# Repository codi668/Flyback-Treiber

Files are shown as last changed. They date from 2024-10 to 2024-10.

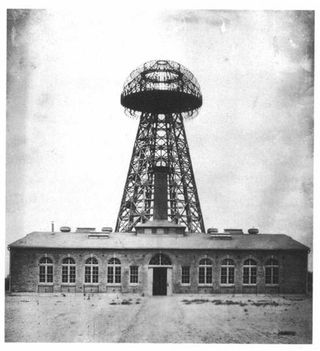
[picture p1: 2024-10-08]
Libaries/wardencliif.jpeg

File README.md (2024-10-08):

# Flyback Musik-Treiber

Dieses Projekt verwendet einen Flyback-Treiber, um Musiksignale zu erzeugen und diese über Zeilentrafos auszugeben. Der Flyback-Treiber moduliert das Audiosignal und überträgt es an den Zeilentrafo, der die Musik in hörbare Geräusche umwandelt. Dieses Setup eignet sich für experimentelle Audioprojekte oder künstlerische Installationen.

## Funktionsweise

Der Flyback-Treiber empfängt analoge Audiosignale (zum Beispiel von einem Musikplayer oder einem Synthesizer) und nutzt einen Flyback-Transformator, um diese auf Hochspannungsniveau zu übertragen. Der Zeilentrafo empfängt das modulierte Signal und wandelt es in hörbare Schwingungen um, die als Musik oder Geräusche wahrgenommen werden.

## Features

- **Audio-Ausgabe:** Musik wird über Zeilentrafos ausgegeben.
- **Einfache Integration:** Der Treiber lässt sich mit verschiedenen Audioquellen und Verstärkern verbinden.
- **Verstellbare Lautstärke:** Die Lautstärke kann durch Anpassung der Eingangssignale gesteuert werden.
- **Experimentelles Design:** Ideal für künstlerische Projekte oder Sound-Installationen.

## Komponenten

1. **Flyback-Treiber-Modul**: Ein handelsübliches Flyback-Modul, das für die Hochspannungssteuerung verwendet wird.
2. **Zeilentrafo**: Ein Transformator, der zur Erzeugung der hörbaren Töne verwendet wird.
3. **Audioquelle**: Ein Gerät, das über 3,5mm Klinkenanschluss Musik wiedergibt (z. B. Smartphone, Laptop, etc.).
4. **Stromversorgung**: Ein Netzteil, das 12V bis 24V DC liefert (je nach Flyback-Modul).
5. **Kabel**: Zur Verbindung der Audioquelle, des Flyback-Treibers und des Zeilentrafos.

## Installationsanleitung

### Benötigte Materialien

- **Flyback-Treiber-Modul** (z.B. aus einem alten CRT-Monitor oder TV)
- **Zeilentrafo** (aus einem Fernseher oder Monitor)
- **Audioquelle** (mit 3,5mm Klinkenanschluss)
- **Netzteil** (12V-24V DC, abhängig vom Flyback-Modul)
- **Kabel und Stecker** (zur Verbindung der Komponenten)
- **Sicherheitsvorkehrungen** (Isoliermaterialien und Schutzvorkehrungen gegen Hochspannung)

### Schritt-für-Schritt-Anleitung

1. **Flyback-Treiber anschließen**:
   - Verbinde den Eingang des Flyback-Moduls mit einer 12V bis 24V DC-Stromquelle.
   - Verbinde das Audioeingangssignal (z. B. über einen 3,5mm Klinkenstecker) mit der Audioquelle (Smartphone, Laptop, etc.).

2. **Zeilentrafo anschließen**:
   - Der Ausgang des Flyback-Transformators wird an die Eingänge des Zeilentrafos angeschlossen.

3. **Testen**:
   - Spiele Musik von deiner Audioquelle ab und höre, wie das Signal über den Zeilentrafo ausgegeben wird.

## Sicherheitshinweise

- **Hochspannung**: Der Flyback-Treiber erzeugt Hochspannungen. Arbeite daher sehr vorsichtig und befolge alle Sicherheitsvorkehrungen, um Verletzungen durch Stromschläge zu vermeiden.
- **Isolierung**: Stelle sicher, dass alle Hochspannungsleitungen gut isoliert sind und keine Kurzschlüsse entstehen.
- **Schutzbrille und Handschuhe**: Trage immer Schutzbrille und isolierende Handschuhe, wenn du mit Hochspannung arbeitest.

## Anwendungen

- **Experimentelle Musikprojekte**: Nutze den Flyback-Treiber zur Erzeugung einzigartiger Klänge in einer Musikinstallation.
- **Kunstinstallationen**: Setze die Technologie in interaktive oder künstlerische Audioprojekte ein.
- **Prototyping**: Nutze das Setup als Grundlage für eigene Experimente im Bereich Audio- und Elektrotechnik.

## Lizenz

Dieses Projekt ist unter der MIT-Lizenz lizenziert. Siehe [LICENSE](LICENSE) für weitere Details.

## Kontakt

- **E-Mail:** thomas.gruber@htlstp.at
- **GitHub:** github.com/codi668

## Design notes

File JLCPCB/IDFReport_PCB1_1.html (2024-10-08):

Altium customize

# IDF File Translation Report

Date: | | 02.10.2024
Time: | | 19:26:28
Elapsed Time: | | 00:00:00
PCB Filename | : | D:\privat\Altium\Flyback\PCB1.PcbDoc
IDF Board Filename | : | C:\Users\t2022\Downloads\PCB1_1.brd
IDF Library Filename | : | C:\Users\t2022\Downloads\PCB1_1.pro

Errors

Back to top

Warnings

Back to top

Save Warnings

Back to top

Save Errors

Back to top

Export Warnings

Back to top

Export Errors

Back to top

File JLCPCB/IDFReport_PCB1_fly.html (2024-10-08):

Altium customize

# IDF File Translation Report

Date: | | 02.10.2024
Time: | | 19:20:07
Elapsed Time: | | 00:00:00
PCB Filename | : | D:\privat\Altium\Flyback\PCB1.PcbDoc
IDF Board Filename | : | C:\Users\t2022\Downloads\PCB1_fly.brd
IDF Library Filename | : | C:\Users\t2022\Downloads\PCB1_fly.pro

Errors

Back to top

Warnings

Back to top

Save Warnings

Back to top

Save Errors

Back to top

Export Warnings

Back to top

Export Errors

Back to top

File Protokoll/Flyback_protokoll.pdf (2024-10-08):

# Flyback Treiber

By Thomas Gruber

## Inhaltsverzeichnis

## Idee:

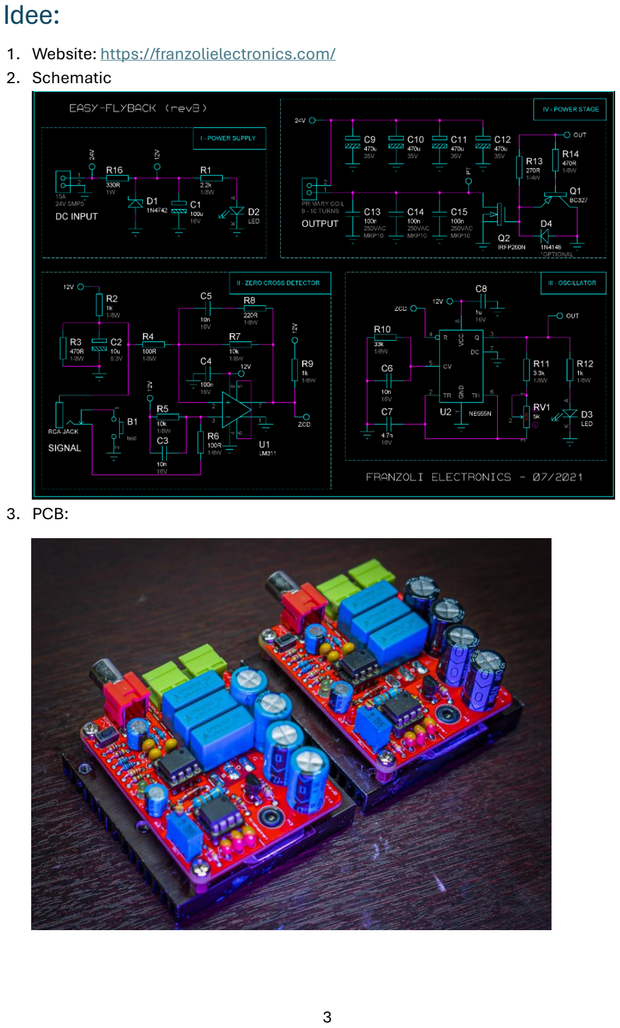
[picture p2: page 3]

1. Website: https://franzolielectronics.com/
2. Schematic
3. PCB:

## Desing:

## Optimierung:

Statt 2 Treiber zu bauen die einen altmodischen RC-Jack wird ein Aux- Klinken Stecker verwendet, um ein PCB zu bauen welches zwei Zeilentransformatoren auf einmal steuern kann.
Außerdem werden statt TH (Through Hole) auf SMD (Surface Mountet Device) umgestiegen werden, um Platz zu sparen. Dazu werden der Oszillator und der Eingang der Schaltung um designend.

## Bauteilbeschaffung:

Für die Bauteilbeschaffung wurde Aliexpress verwendet und für die jeweiligen Footprint und Schematic wurde SnapIDE verwendet (ein kontenlose Online-Dienst, welcher sämtlich Bauteil libraries zur Verfügung stellt). Dabei sind Kosten in der Höhe von 80€ entstanden. Dazu wurde auch eine Excel-Liste (https://htlstp-my.sharepoint.com/personal/20220061_htlstp_at/Documents/Flyback-st%C3%BCckliste_1.xlsx?web=1) erstellt.

## Altium:

Für die Zeichnung der Schematic und die Entflechtung wurde der Altium-desinger verwendet.

## Eigene Library:

Da es nicht für alle Bauteile einen Footprint und eine Schematic gab wurde eine extra Library für dieses Projekt erstellt.

## Schematic:

Die Schematic wurde abgezeichnet von dem bereits existieren Schematic und die Optimierungsvorschläge wurden eingebracht.
1. Stromversorgung (Power Supply)
Der erste Block stellt die Gleichstromversorgung der Schaltung sicher. Ein 1W Widerstand wird als Spannungsteiler verwendet und eine LED hängt in der Schaltung um die Funktion der Schaltung im Betrieb zu bestätigen. Die restlichen Schaltungsblöcke mit stabiler Spannung versorgt.
2. Verstärker (Amplifier)
Die Schaltung enthält zwei Verstärkerstufen, die auf Operationsverstärkern basieren. Diese Verstärker sind mit Widerständen und Kondensatoren beschaltet, die die Verstärkung und die Frequenzcharakteristik bestimmen. Die Verstärkerstufen dienen dazu, schwache Eingangssignale zu verstärken, um sie für die weitere Verarbeitung und für die Leistungsstufe vorzubereiten.

3. Oszillator (Oscillator)
Es sind zwei Oszillatoren auf Basis eines Timer-ICs (NE555N) integriert. Diese erzeugen periodische Ausgangssignale, die als Taktgeber oder zur Erzeugung von Audiosignalen genutzt werden können. Die Frequenz dieser Oszillatoren wird durch die Auswahl von Widerständen und Kondensatoren festgelegt. Diese Signale werden an die Verstärker weitergeleitet.
4. Leistungsstufe (Power Stage)
Die letzte Stufe der Schaltung ist die Leistungsstufe. Hier werden Transistoren verwendet, um das verstärkte Signal mit genügend Stromkapazität zu versehen, um größere Lasten zu treiben. Die Transistoren agieren als Schalter oder Verstärker.
Gesamtfunktion
Die Schaltung dient dazu, ein schwaches Eingangssignal durch die Verstärkerstufen zu verstärken, ein periodisches Signal durch die Oszillatoren zu erzeugen und das verstärkte Signal über die Leistungsstufe an eine Last auszugeben. Die Stromversorgung stellt sicher, dass alle Schaltungsblöcke mit stabiler Gleichspannung versorgt werden, um den Betrieb der Verstärker, Oszillatoren und Leistungsstufe zu gewährleisten.

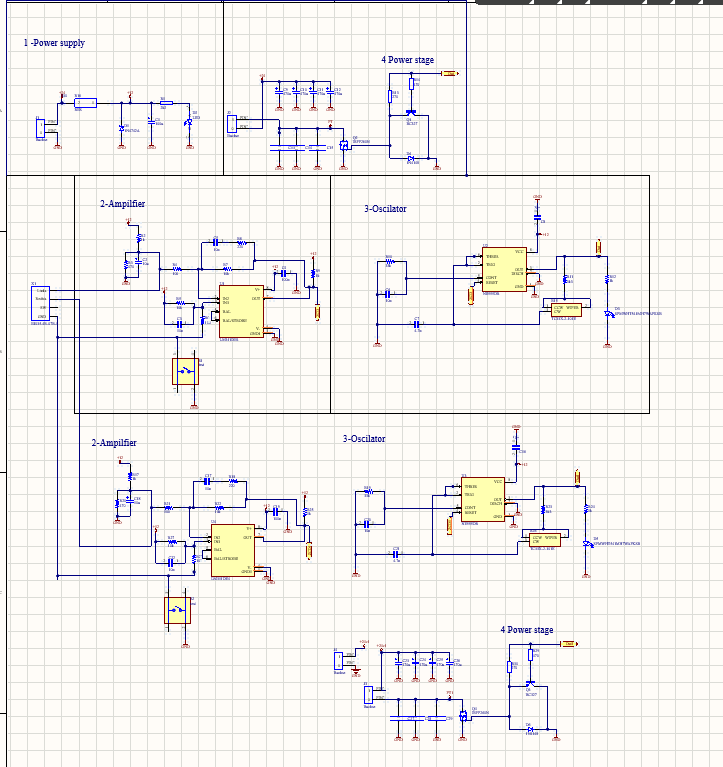
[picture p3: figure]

Abbildung 1: Schematik

## PCB:

Das PCB-Design einer Leiterplatte mit der Bezeichnung M.P.Fly V0.1, wurde von Thomas Gruber entworfen. Die Platine ist für eine Schaltung ausgelegt, die verschiedene elektronische Komponenten zur Signalverarbeitung und Stromversorgung enthält.

1. Stromversorgung:
- Es sind Anschlüsse für eine 12V Stromversorgung (C2) vorhanden. Kondensatoren (C25 bis C29) dienen zur Glättung der Spannung.
- Die Platine stellt auch eine +24V Stromversorgung zur Verfügung, mit den entsprechenden Kondensatoren (C24 bis C29) zur erzeugen der Funken.
2. Aktive Komponenten:
- Es befinden sich Transistoren (Q1, Q2) auf der Platine, sind für die Verstärkung oder Schaltung von Signalen zuständig sind.
- Ein Operationsverstärker (U3) ist in die Schaltung integriert, um Signalverarbeitungsfunktionen zu übernehmen.
3. Passivkomponenten:
- Diverse Widerstände (R1 bis R30) und Kondensatoren (C2 bis C29) sind auf der Platine platziert, um die Signale zu filtern und die Spannungen zu regulieren.
4. Schnittstellen und Steckverbinder:
- Es sind mehrere Steckverbinder vorhanden, darunter J1, J2 und J3, deren Funktion es ist als Ein- und Ausgang zu dienen.
5. Markierungen:
- Auf der Platine sind die Schriftzüge HTL ST. PÖLTEN und der Hinweis designed by Thomas Gruber sichtbar, was auf die Designherkunft und die Entwicklung der Schaltung hinweist.
Zusammenfassung:
Die Platine dient der Signalverarbeitung und Stromversorgung für eine Flyback-Treiber welcher Musik durch Frequenz spielen kann. Sie enthält Transistoren, Operationsverstärker, Widerstände und Kondensatoren für die Spannungsstabilisierung und Filterung von Signalen. Es sind mehrere Steckverbinder vorhanden, die für externe Verbindungen und die Stromversorgung genutzt werden.

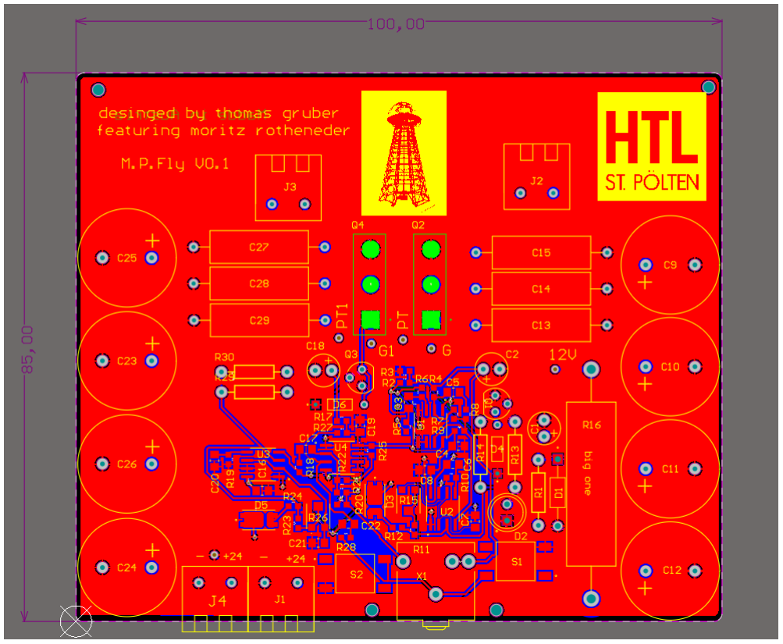
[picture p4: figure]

Abbildung 2: PCB

## Bestellung:

Es wurde eine Bestellung bei JLCBCP aufgegeben. In dieser wurde die Platine bestellt. Als Farbe des PCBs wurde Schwarz gewählt sonst wurden bei allen anderen Einstellungen die Standards der Industrie verwendet, respektive FR-4 Material, weißer Silkscreen 1 Unze Leiterbahnen höhe und Flying Probe Fully Test. Außerdem wurde kein PCB Assembly und kein Stencil gekauft da alle Bauteile bereits bereit waren.
Das Vertigungs-file kann man in Abbildung 4 sehen.
Die Bestellung war der Verhältnisse nach billig und so musste für das PCB nur 2$ umgerechnet 1,82€ ohne Versand bezahlt werden.

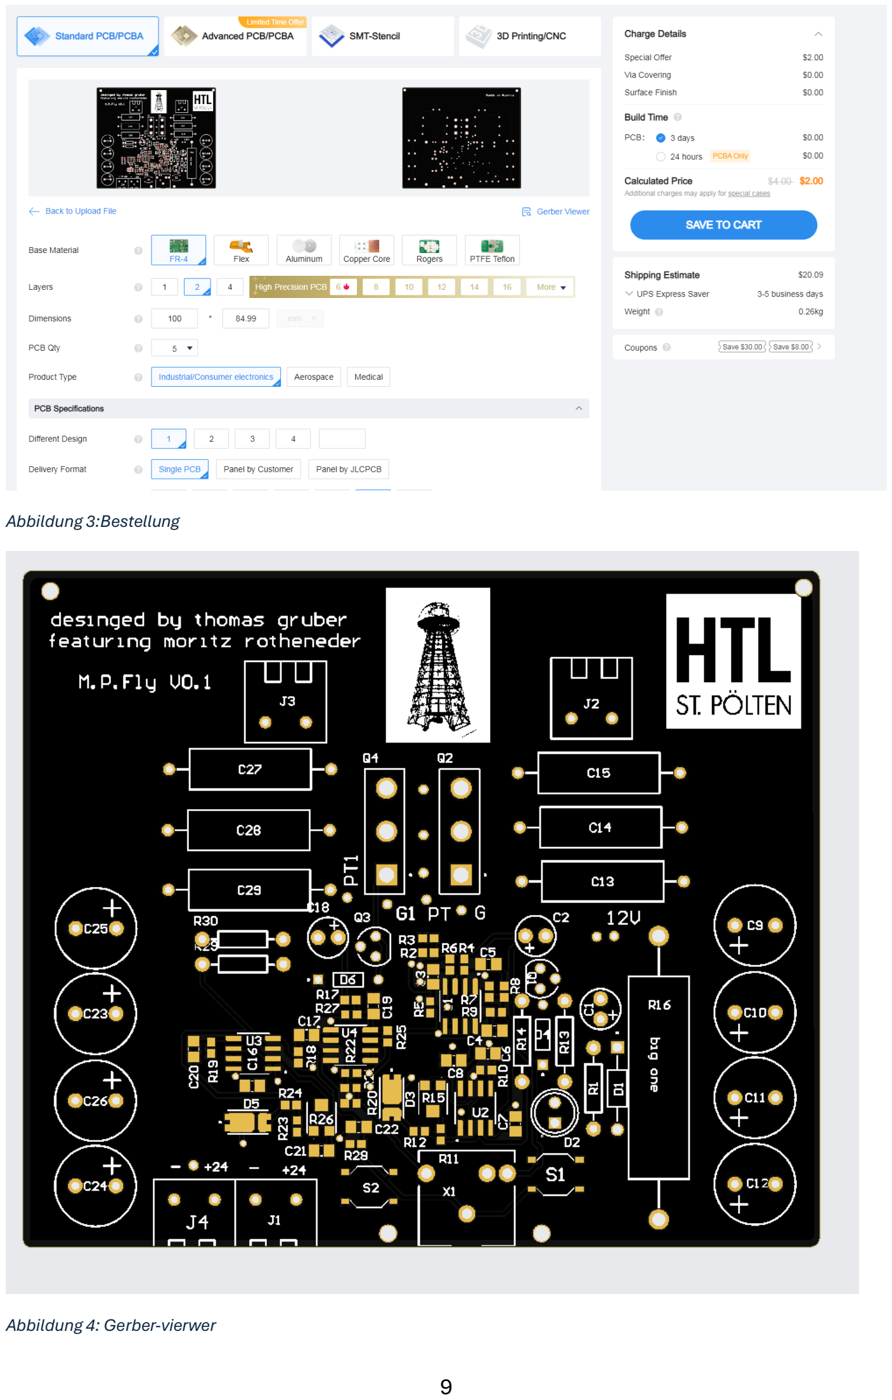
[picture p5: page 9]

Abbildung 3:Bestellung

Abbildung 4: Gerber-vierwer

## Gehäuse:

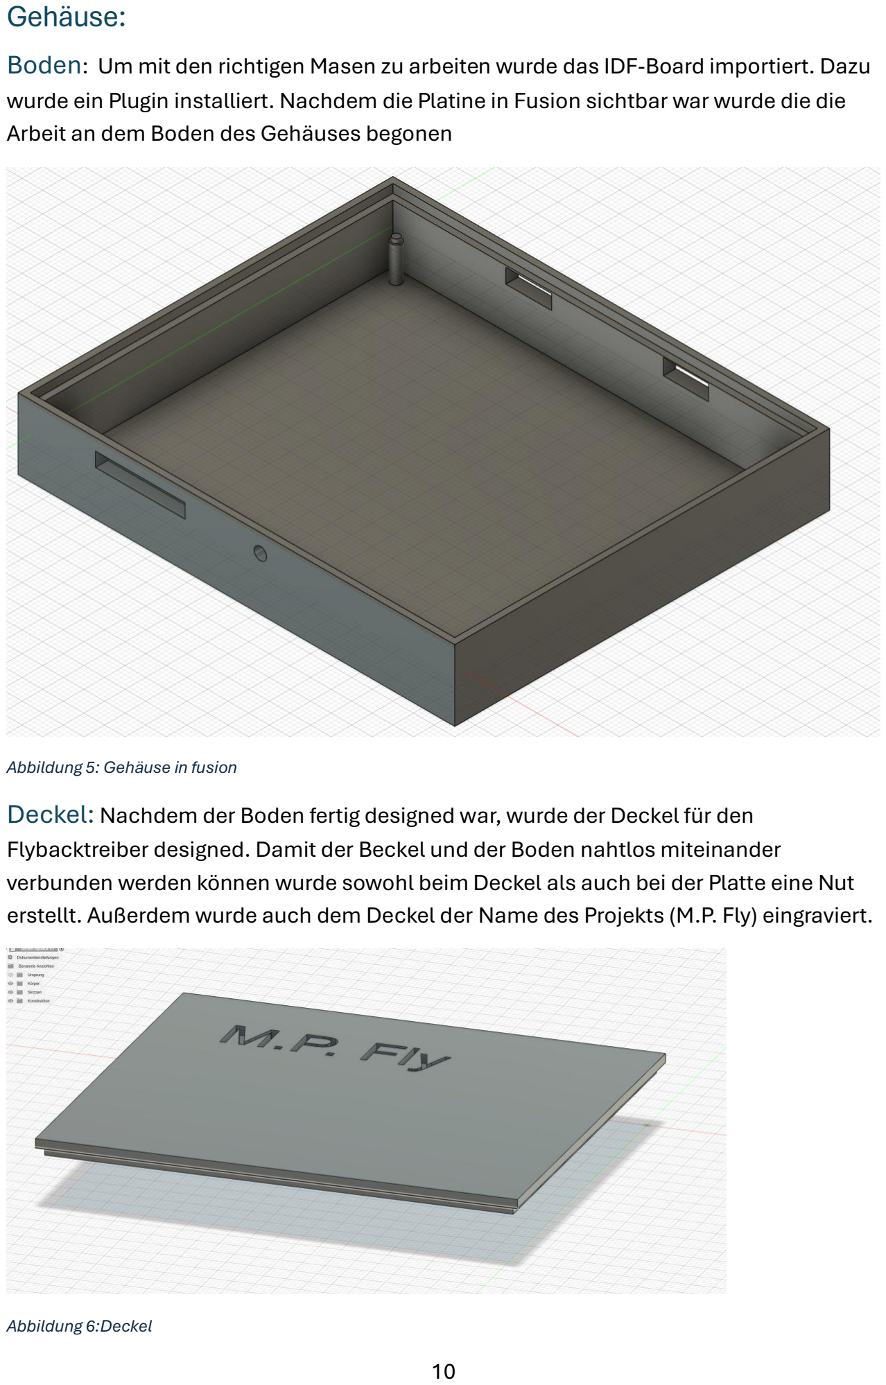
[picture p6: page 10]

Boden: Um mit den richtigen Masen zu arbeiten wurde das IDF-Board importiert. Dazu wurde ein Plugin installiert. Nachdem die Platine in Fusion sichtbar war wurde die die Arbeit an dem Boden des Gehäuses begonen

Abbildung 5: Gehäuse in fusion
Deckel: Nachdem der Boden fertig designed war, wurde der Deckel für den Flybacktreiber designed. Damit der Beckel und der Boden nahtlos miteinander verbunden werden können wurde sowohl beim Deckel als auch bei der Platte eine Nut erstellt. Außerdem wurde auch dem Deckel der Name des Projekts (M.P. Fly) eingraviert.

Abbildung 6:Deckel

GitHub: Alle verwendeten Dokumente wurden auf GitHub (https://github.com/codi668/Flyback-Treiber) hochgeladen. Damit können auch andere diesen Flybacktreiber nachbauen.

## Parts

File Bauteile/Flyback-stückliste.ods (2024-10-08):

Bauteil | Spesifikation | Designator | SMD/TH | Lieferant | Library | Link
2.2k | 1/8W | R1 | Bedrahtet | Bauteilkiste | schule
1k | 1/8W | R2 | SMD/0603 | ali | snap | https://www.aliexpress.com/store/1103180004?sortType=bestmatch_sort
470R | 1/8W | R3 | SMD/0603 | ali | snap | https://www.aliexpress.com/store/1103180004?sortType=bestmatch_sort
100R | 1/8W | R4 | SMD/0603 | ali | snap | https://www.aliexpress.com/store/1103180004?sortType=bestmatch_sort
10k | 1/8W | R5 | SMD/0603 | ali | snap | https://www.aliexpress.com/store/1103180004?sortType=bestmatch_sort
100R | 1/8W | R6 | SMD/0603 | ali | snap | https://www.aliexpress.com/store/1103180004?sortType=bestmatch_sort
10k | 1/8W | R7 | SMD/0603 | ali | snap | https://www.aliexpress.com/store/1103180004?sortType=bestmatch_sort
220R | 1/8W | R8 | SMD/0603 | ali | snap | https://www.aliexpress.com/store/1103180004?sortType=bestmatch_sort
1k | 1/8W | R9 | SMD/0603 | ali | snap | https://www.aliexpress.com/store/1103180004?sortType=bestmatch_sort
33k | 1/8W | R10 | SMD/0603 | ali | snap | https://www.aliexpress.com/store/1103180004?sortType=bestmatch_sort
3.3k | 1/8W | R11 | SMD/0603 | ali | snap | https://www.aliexpress.com/store/1103180004?sortType=bestmatch_sort
1k | 1/8W | R12 | SMD/0603 | ali | snap | https://www.aliexpress.com/store/1103180004?sortType=bestmatch_sort
270R | 1/4W | R13 | Bedrahtet | Bauteilkiste | schule
470R | 1/8W | R14 | Bedrahtet | Bauteilkiste | schule
330R | 1W | R16 | Bedrahtet | vorhanden | ich
2k7 | 25W | R? | Bedrahtet | BAUTEILKeller | nichtvorhanden
100u | 16V Elko | C1 | Bedrahtet | vorhanden | schule
10u | 3.6V Elko | C2 | Bedrahtet | vorhanden | schule
10n | 16V | C3 | SMD/0805 | aliexpress | snap | https://de.aliexpress.com/item/1005002770949160.html
100n | 16V | C4 | SMD/0805 | aliexpress | snap | https://de.aliexpress.com/item/1005002770949160.html
10n | 16V | C5 | SMD/0805 | aliexpress | snap | https://de.aliexpress.com/item/1005002770949160.html
10n | 16V | C6 | SMD/0805 | aliexpress | snap | https://de.aliexpress.com/item/1005002770949160.html
4.7n | 16V | C7 | SMD/0805 | aliexpress | snap | https://de.aliexpress.com/item/1005002770949160.html
1u | 16V | C8 | SMD/0805 | aliexpress | snap | https://de.aliexpress.com/item/1005002770949160.html
470u | 35V Elko | C9 | Bedrahtet | vorhanden | schule
470u | 35V Elko | C10 | Bedrahtet | vorhanden | schule
470u | 35V Elko | C11 | Bedrahtet | vorhanden | schule
470u | 35V Elko | C12 | Bedrahtet | vorhanden | schule
100n | 250VACMKP10 | C13 | Bedrahtet | vorhanden | ich
100n | 250VACMKP10 | C14 | Bedrahtet | vorhanden | ich
100n | 250VACMKP10 | C15 | Bedrahtet | vorhanden | ich
DIODE | 1N4742 | D1 | Bedrahtet | aliexpress | snap | https://de.aliexpress.com/item/1005004984138449.html?mp=1
DIODE | LED | D2 | Bedrahtet | Bauteilkiste | snap
DIODE | LED | D3 | SMD | aliexpress | snap | https://de.aliexpress.com/item/4000398868522.html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
DIODE | 1N4148 | D4 | Bedrahtet | aliexpress | snap | https://de.aliexpress.com/item/4000142272546.html?mp=1
TRANSISTOR | BC327 | Q1 | Bedrahtet | RS | snap | https://at.rs-online.com/web/p/bipolare-transistoren/6711107
MOSFET | IRFP260N | Q2 | Bedrahtet | amazon | snap | https://www.amazon.de/BOJACK-MOSFET-Transistoren-IRFP260N-N-Kanal-Leistungs-MOSFET-IRFP260NPBF/dp/B086C1JZPJ
 | Taster | B1 | SMD | RS | snap | https://at.rs-online.com/web/p/tastschalter/2707936
5k | Poti | RV1 | SMD | RS | snap | https://at.rs-online.com/web/p/trimmerpotentiometer/6696682
NE555N | Timer | IC | SMD | aliexpress | snap | https://de.aliexpress.com/item/1005002882751149.html
LM311 |  | IC | SMD | aliexpress | snap | https://de.aliexpress.com/item/1005005726220962.html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
Buchse | Aux | X1 | Bedrahtet | vorhanden | ich
Buchse | DC | J1 | Bedrahtet | vllt.schule
Buchse | AC | J2 | Bedrahtet | vllt.schule
 |  |  | Kosten: | aliexpress | 61,44
 |  |  |  | RS | 11
 |  |  |  | amazon | 11
 |  |  |  | insgesamt | 83 €

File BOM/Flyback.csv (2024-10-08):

Comment | Description | Designator | Footprint | LibRef | Quantity
ELKO | Elko | C1, C2, C18 | RB-.1/.2 | ELKO | 3
GCM21BR71H104KA37K | SMD Capacitor X7R(EIA) with Capacitance: 0.10uF Tol. 10%. Rated Voltage: 50Vdc, [NoValue] | C3, C4, C5, C6, C7, C17, C19, C20, C21, C22 | CAPC2012X135N | GCM21BR71H104KA37K | 10
10u | SMD Capacitor X7R(EIA) with Capacitance: 0.10uF Tol. 10%. Rated Voltage: 50Vdc | C8, C16 | CAPC2012X135N | GCM21BR71H104KA37K | 2
ELKO | Elko | C9, C10, C11, C12, C23, C24, C25, C26 | RB-.2/.4 | ELKO | 8
Kondensator |  | C13, C14, C15, C27, C28, C29 | Co | Kondensator | 6
1N4742A | Zener Diode 12 V 1 W ±5% Through Hole DO-41 | D1 | DIOAD1036W78L463D272 | 1N4742A | 1
LED | Red 617nm LED Indication - Discrete 2V Radial | D2 | LED_WP7113ID | WP7113ID | 1
SPMWHT541MH7WAPKSB | LED LM561B PLUS WHITE 5630 | D3, D5 | LED_SPMWHT541MH7WAPKSB | SPMWHT541MH7WAPKSB | 2
1N4148 |  | D4, D6 | DIOAD753W49L380D172B | 1N4148 | 2
Buchse |  | J1, J2, J3, J4 | Buchse1 | Buchse | 4
BC327 | Bipolar (BJT) Transistor PNP 45V 800mA 260MHz 625mW Through Hole TO-92 (TO-226) | Q1, Q3 | SOT54A | BC327 | 2
IRFP260N | N-Channel 200V 50A (Tc) 300W (Tc) Through Hole TO-247AC | Q2, Q4 | TO545P1560X500X2460-3 | IRFP260N | 2
1/8W | Widerstand | R1, R14, R29 | Axial-0.4 | RES | 3
RC0603FR-071ML | Thick film general purpose | R2, R3, R4, R5, R6, R7, R8, R9, R10, R11, R12, R17, R18, R19, R20, R21, R22, R23, R24, R25, R27, R28 | RESC1607X60N | RC0603FR-071ML | 22
1/4W | Widerstand | R13, R30 | Axial-0.4 | RES | 2
TC33X-2-101E | Resistor | R15, R26 | TC33X2503E | TC33X-2-101E | 2
RES |  | R16 | PCBComponent_1 | RES | 1
SMD-BUTTON(4P-5.2X5.2X1.5MM-SKQGAKE010) | Switch Tactile N.O. SPST Button Gull Wing 0.05A 12VDC 3.43N SMD T/R | S1, S2 | SW4-SMD-5.2X5.2X1.5MM | SMD-BUTTON(4P-5.2X5.2X1.5MM-SKQGAKE010) | 2
LM311DE4 | High Speed, 30V, Differential Comparator With Strobes 8-SOIC 0 to 70 | U1, U4 | SOIC127P599X175-8N | LM311DE4 | 2
NE555DR |  | U2, U3 | SOIC127P599X175-8N | NE555DR | 2
EJ035-4R-07R-1 | HTL-Schnorr-Elektronik | X1 | EJ035-4R-07R-1 | 3.5mm Klinke Stereo | 1
